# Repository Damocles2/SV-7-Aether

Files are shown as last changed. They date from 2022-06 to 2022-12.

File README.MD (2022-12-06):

header2 blackandwhite
****
## A revolutionary tool ##

The SV-7 is a small and lightweight handheld laser device, comprised of a 3d printed alluminium lower that serves as the device's heatsink and structure, as well as a pla cover that connects to it through a screwless assembly system.

Although it might look unasuming, it's tiny PCB is capable of providing up to 15w at a stable 5v with a single squeeze of it's pressure sensitive resistor

## Timeless design ##

The SV-7 might look simple at first glance, but a closer look will reveal that it's anything but. The design's attention to detail is showcased in the contrast between the smooth, beveled white, and the sleek metallic lower
mini

And at only 18mm thick, it can easily fit in most large pockets

## Powerful and flexible hardware ##

The device's heart and brains are all contained within a tiny and highly dense pcb, fitting snugly within the device and effortlessly combining the high power/frequency power circuitry (boost converter,charger,high current transistor) with a highly flexible attiny chip, taking away the burden of having to stuff multiple modules inside of the elegant case, and allowing you to simply connect all 3 components and modify the resistor's sensitivity/safety features to your liking.

And with a 1a tp4056 charging IC, you can quickly charge it's 18650 or AA(A) cell with ease



## Simple yet modular ##

The metal base can support a wide range of laser and lenses depending on your needs. Although designed for 9mm lasers, the design can easily be changed to suit lower power 5.6mm lasers.

Gun bottom

It also sports a carefully designed heatsink, designed to wick away the massive amounts of excess heat a powerful diode can produce

**⚠️ Alternatively, if the high cost of metal 3d printing isn't acceptable, both part can be produced with 3d printed polycarbonate, filled with mineral oil, and sealed. The diode mount can be hot glued to the top plastic to form a seal as not to have the oil affect the beam. ⚠️**

## Affordable ##

**Metal chassis**: <100$

**Top cover**: around 10 if you're having it printed online, otherwise <1$

**Populated PCB**: ~15$

**18650 battery** ~1.5$

**Collimating lens (optional):** ~1.99$ on aliexpress

**Trigger**: Any thin film pressure sensor would work if you set the right resistance. The sv-7 is designed for a long strip type unit (like the zd10-100), but a smaller circular one (eg: RP-C7.6-ST) is a far safer and more practical solution, if not quite as cool.

The device can be a little too front heavy for some users, so tungsten putty, available in most online marketplaces (eg: aliexpress) and fishing stores, can be added to the grip until an adequate balance is achieved.

The device itself should only cost about 125 dollars, however your price heavily depends on the diode you are using. I reccomend the SHARP GH04C05Y9G, which can be had on aliexpress for only 38.99$

This puts the total at a surprisingly low 140$ (with a metal chassis, see above for advice on producing plastic lower)

## A wide range of applications ##

As this is essentialy just a handheld laser diode with a comfortable grip, it can be used in various fields to perform a countless variety of tasks.

- Military use 
- Law enforcement use (for non lethal crowd control without a collimating lens)
- Self defence
- Engineering
- Mining (as a precision instrument)

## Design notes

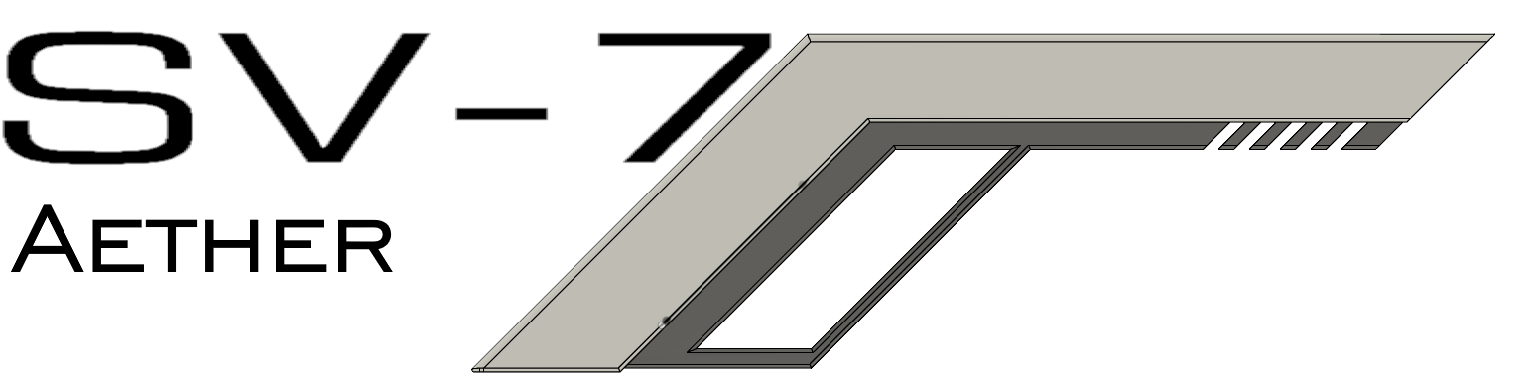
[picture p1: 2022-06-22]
Images/Imagetop.png

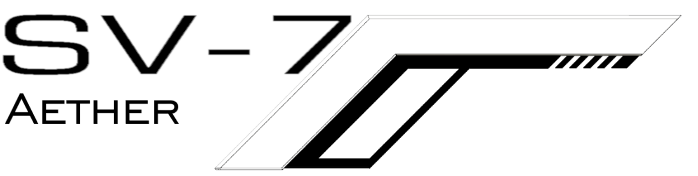
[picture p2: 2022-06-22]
Images/header2 blackandwhite.png

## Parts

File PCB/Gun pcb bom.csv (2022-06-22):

Id | Designator | Package | Quantity | Designation | Supplier and ref
1 | BT1 | TestPoint_2Pads_Pitch2.54mm_Drill0.8mm | 1 | Battery_Cell
2 | C1,C5,C7 | C_0805_2012Metric_Pad1.18x1.45mm_HandSolder | 3 | 22uF
3 | C2,C8 | C_0805_2012Metric_Pad1.18x1.45mm_HandSolder | 2 | 0.1uF
4 | C3 | C_0805_2012Metric_Pad1.18x1.45mm_HandSolder | 1 | 200pF
5 | C4,C6 | C_0805_2012Metric_Pad1.18x1.45mm_HandSolder | 2 | 10uF
6 | D1 | D_SMC | 1 | ss34
7 | D2 | LED_0603_1608Metric_Pad1.05x0.95mm_HandSolder | 1 | LED
8 | J1 | USB_Micro-B_Amphenol_10118194_Horizontal | 1 | USB_B_Micro
9 | L1 | L_Bourns_SRR1260 | 1 | 22uH
10 | LD1 | TestPoint_2Pads_Pitch2.54mm_Drill0.8mm | 1 | High power laser diode
11 | Q1 | TO-220-3_Vertical | 1 | TIP120
12 | R1 | R_0603_1608Metric_Pad0.98x0.95mm_HandSolder | 1 | 1.2k
13 | R2 | R_0603_1608Metric_Pad0.98x0.95mm_HandSolder | 1 | 5k
14 | R3 | R_0603_1608Metric_Pad0.98x0.95mm_HandSolder | 1 | 1k
15 | R4 | R_0603_1608Metric_Pad0.98x0.95mm_HandSolder | 1 | 3.6k
16 | R5 | R_0603_1608Metric_Pad0.98x0.95mm_HandSolder | 1 | 1.3k
17 | R6 | R_0603_1608Metric_Pad0.98x0.95mm_HandSolder | 1 | 0.4 ohm
18 | R7 | R_0603_1608Metric_Pad0.98x0.95mm_HandSolder | 1 | 2.2k
19 | R8 | TestPoint_2Pads_Pitch2.54mm_Drill0.8mm | 1 | FSR
20 | R9 | R_0603_1608Metric_Pad0.98x0.95mm_HandSolder | 1 | 10k
21 | U1 | SOIC-8-1EP_3.9x4.9mm_P1.27mm_EP2.29x3mm | 1 | cs5171
22 | U2 | SOIC-8-1EP_3.9x4.9mm_P1.27mm_EP2.29x3mm_ThermalVias | 1 | TP4056
23 | U3 | SOIJ-8_5.3x5.3mm_P1.27mm | 1 | ATtiny25-20SU

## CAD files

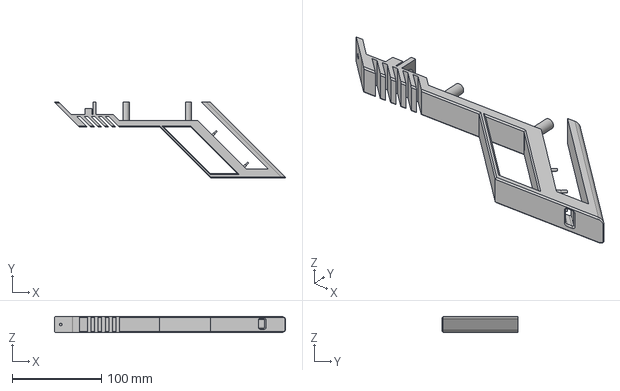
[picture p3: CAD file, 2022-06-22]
Solid parts/Gun bottom (alumium).step
259.3 x 85.0 x 18.0 mm

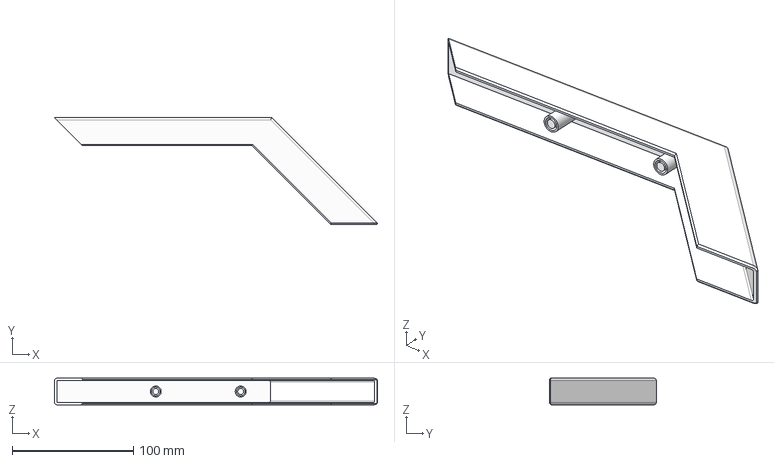
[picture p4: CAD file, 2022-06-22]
Solid parts/Top cover (plastic).step
266.3 x 88.0 x 22.0 mm

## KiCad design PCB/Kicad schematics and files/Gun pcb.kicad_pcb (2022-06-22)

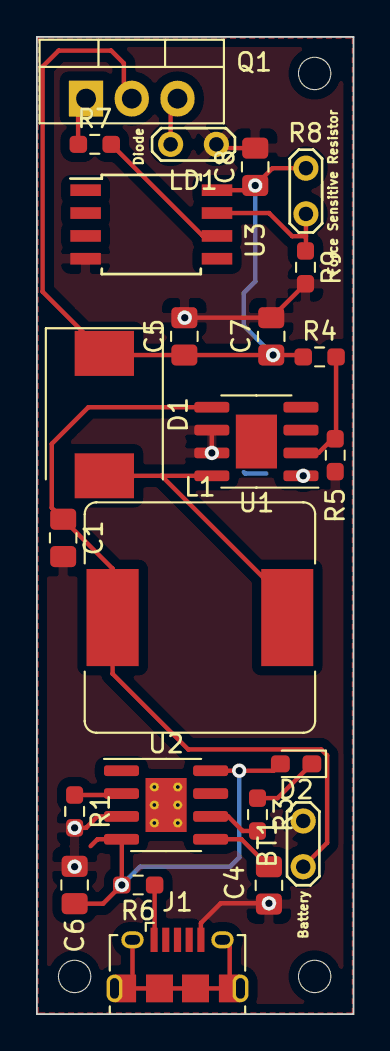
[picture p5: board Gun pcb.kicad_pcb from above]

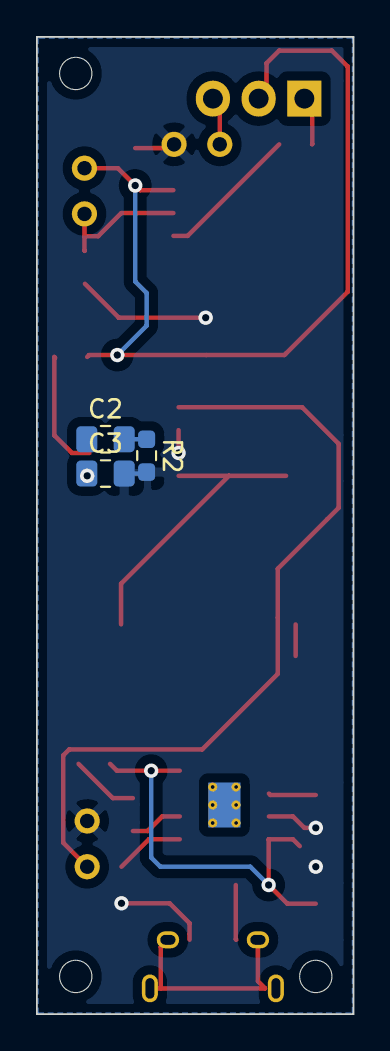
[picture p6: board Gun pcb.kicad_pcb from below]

Board: 2 copper layers, 17.6 x 54.3 mm, 27 parts (3 on the bottom side), 16 nets.

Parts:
BT1: Battery_Cell; TestPoint_2Pads_Pitch2.54mm_Drill0.8mm
C1, C5, C7: 22uF; C_0805_2012Metric_Pad1.18x1.45mm_HandSolder
C2, C8: 0.1uF; C_0805_2012Metric_Pad1.18x1.45mm_HandSolder
C3: 200pF; C_0805_2012Metric_Pad1.18x1.45mm_HandSolder
C4, C6: 10uF; C_0805_2012Metric_Pad1.18x1.45mm_HandSolder
D1: ss34; D_SMC
D2: LED; LED_0603_1608Metric_Pad1.05x0.95mm_HandSolder
J1: USB_B_Micro; USB_Micro-B_Amphenol_10118194_Horizontal
L1: 22uH; L_Bourns_SRR1260
LD1: High power laser diode; TestPoint_2Pads_Pitch2.54mm_Drill0.8mm
Q1: TIP120; TO-220-3_Vertical
R1: 1.2k; R_0603_1608Metric_Pad0.98x0.95mm_HandSolder
R2: 5k; R_0603_1608Metric_Pad0.98x0.95mm_HandSolder
R3: 1k; R_0603_1608Metric_Pad0.98x0.95mm_HandSolder
R4: 3.6k; R_0603_1608Metric_Pad0.98x0.95mm_HandSolder
R5: 1.3k; R_0603_1608Metric_Pad0.98x0.95mm_HandSolder
R6: 0.4 ohm; R_0603_1608Metric_Pad0.98x0.95mm_HandSolder
R7: 2.2k; R_0603_1608Metric_Pad0.98x0.95mm_HandSolder
R8: FSR; TestPoint_2Pads_Pitch2.54mm_Drill0.8mm
R9: 10k; R_0603_1608Metric_Pad0.98x0.95mm_HandSolder
U1: cs5171; SOIC-8-1EP_3.9x4.9mm_P1.27mm_EP2.29x3mm
U2: TP4056; SOIC-8-1EP_3.9x4.9mm_P1.27mm_EP2.29x3mm_ThermalVias
U3: ATtiny25-20SU; SOIJ-8_5.3x5.3mm_P1.27mm

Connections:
+5V: C5.1, C7.1, C8.1, D1.1, Q1.2, R4.1, R8.1, U3.8
+BATT: BT1.1, C1.1, C4.1, L1.1, U1.5, U2.5
GND: BT1.2, C1.2, C3.2, C4.2, C5.2, C6.2, C7.2, C8.2, J1.5, LD1.1, R1.2, R2.2, R5.2, R9.2, U1.6, U1.7, U2.3, U3.4
unnamed: C2.1, C3.1, U1.1
unnamed: C2.2, R2.1
unnamed: D1.2, L1.2, U1.8
unnamed: D2.1, R3.1
unnamed: LD1.2, Q1.3
unnamed: Q1.1, R7.1
unnamed: R1.1, U2.2
unnamed: R3.2, U2.6
unnamed: R4.2, R5.1, U1.2
unnamed: R8.2, R9.1, U3.7
VBUS: J1.1, R6.1
VCC: C6.1, D2.2, R6.2, U2.4, U2.8
laser: R7.2, U3.6
